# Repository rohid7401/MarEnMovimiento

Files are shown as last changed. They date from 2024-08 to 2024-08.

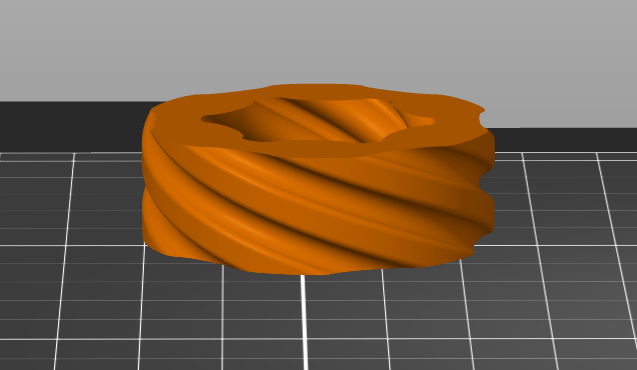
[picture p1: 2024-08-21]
Pruebas/Rosca Front.png

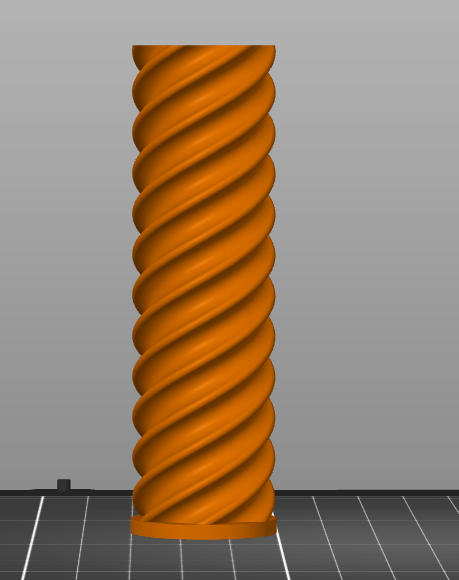
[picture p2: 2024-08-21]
Pruebas/Cilindro Front.png

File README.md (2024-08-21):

# MarEnMovimiento
Proyecto para CENFOTEC por Michelle Gutierrez, Rohi Prendas y Jeaustin  Obando

# **Proyecto: Mar en Movimiento**

## **Descripción**

Este proyecto consiste en un generador de energía que aprovecha el movimiento de las olas atravez de los geiser para producir electricidad. El dispositivo utiliza el movimiento de un cilindro y un sistema de engranajes para convertir la energía cinética de las olas en energía eléctrica. Un puente rectificador convierte la corriente alterna generada por el motor en corriente continua para alimentar LEDs u otros pequeños dispositivos electrónicos.

## **Características del Proyecto**

- **Conversión de Energía Cinética:** El dispositivo convierte el movimiento de las olas en energía eléctrica.
- **Generación en Ambos Sentidos:** Utiliza un puente rectificador para asegurar que la electricidad se genera tanto cuando la ola impacta el dispositivo como cuando el agua retrocede.
- **Indicadores LED:** Los LEDs se utilizan como indicadores visuales para mostrar la energía generada.

## **Componentes del Proyecto**

1. **Motor Generador:** Convierte el movimiento en energía eléctrica.
2. **Puente Rectificador (DF08):** Convierte la corriente alterna del motor en corriente continua.
3. **Capacitor:** Ayuda a estabilizar la salida de corriente.
4. **Engranajes:** Aumentan la eficiencia de la conversión de energía.
5. **LEDs:** Muestran la energía generada.

## **Especificaciones Técnicas**

- **Cilindro:** Crea el movimiento del engranaje que es el que provee energia.
- **Frecuencia de Activación:** Calculada en función del número de subidas y el tiempo.
- **Materiales Resilientes:** Se sugiere el uso de materiales resistentes a la corrosión debido al ambiente marino.

## **Instrucciones de Montaje**

1. **Imprimir las Piezas en 3D:**
   - Cilindro con forma de tornillo.
   - Engranajes.
   - Carcasa para mantener los componentes
   
2. **Montaje del Sistema:**
   - Conectar el motor a los engranajes.
   - Conectar el puente rectificador al motor.
   - Colocar el capacitor y los LEDs en paralelo con la salida del puente rectificador.

3. **Instalación del Dispositivo en el Agua:**
   - Asegúrate de que el dispositivo esté bien sellado para evitar daños por el agua.
   - Fija el dispositivo en una ubicación donde reciba el impacto de las olas.

## **Funcionamiento**

El dispositivo se activa con el impacto del agua disparada por el geiser. El motor genera electricidad que es convertida en corriente continua por el puente rectificador, alimentando así los LEDs. La frecuencia con la que se activa el dispositivo depende del movimiento del agua.

## **Pruebas**
Drive de las evidencia de pruebas: https://drive.google.com/drive/folders/1p6oiQmE6wtrTuFcZD503JOJJFgEpMvDa

## **Posibles Mejoras y Extensiones**

- **Implementación de un Joystick:** Para controlar la apertura de la entrada de agua, optimizando la eficiencia del sistema.
- **Análisis de Materiales:** Evaluar el uso de materiales más resistentes para entornos marinos.
- **Ampliación a Gran Escala:** Investigar la viabilidad de escalar el dispositivo para alimentar sistemas más grandes, como una vivienda.

## **Conclusión**

Este proyecto demuestra cómo se puede aprovechar la energía del movimiento del mar para generar electricidad de manera eficiente. Es un prototipo funcional que abre la puerta a futuras investigaciones y desarrollos en el campo de la energía renovable.

## **Autores**

- Michelle Gutierrez Araya
- Rohi Prendas
- Jeaustin  Obando
  
## **Licencia**
Al desarrollar y utilizar este proyecto se aceptaron los terminos y condiciones de la universidad CENFOTEC, y además se establecen los siguientes puntos:

- Uso Libre: Puede usar, copiar, modificar y distribuir el proyecto con cualquier propósito, siempre que se respeten los términos de la licencia.
- Distribución: Si distribuye copias o modificaciones del proyecto, debe incluir una copia de esta licencia.
- Limitación de Responsabilidad: Este proyecto se proporciona "tal cual", sin garantía de ningún tipo, expresa o implícita, incluyendo pero no limitándose a garantías de comerciabilidad, idoneidad para un propósito particular y no infracción.
- Citación: Si utiliza este proyecto en su investigación o trabajo, se recomienda citar al autor y el proyecto como fuente.

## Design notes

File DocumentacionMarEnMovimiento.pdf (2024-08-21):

Mar en movimiento
Tecnológico de Costa Rica

## Título del Proyecto:

## Mar en movimiento

## Energia renovable

# Participación en CENFOTEC

## Fecha: 17/8/2024

## Autores:

## - Michelle Gutiérrez Araya

## - Rohi Prendas Regalado

## - Jeaustin Obando Arias

## Índice

1. Introducción

1.1 Propósito

Este documento es una descripción técnica del proyecto del mar en movimiento. Su objetivo es ayudar a que otros ingenieros, técnicos o investigadores comprendan, puedan replicar y evalúen el proyecto de manera competente.

1.2 Alcance

Se desea desarrollar un prototipo que consiga convertir la energía del agua en electricidad. La

atención se centrará en determinar con qué eficiencia el sistema puede generar energía a

pequeña escala, con el objetivo de permitir su expansión y uso en un entorno práctico. Como

detalle, el prototipo incluye un eje giratorio, engranajes, un motor de corriente continua, un

puente rectificador, RFID, un IDEBOARD y un sistema de indicadores LED.

1.3 Objetivos

- Fabricar un prototipo funcional que capture la energía de las olas.
- Conseguir la mejor eficiencia del sistema utilizando una relación de engranajes

adecuada.

- Aplicar y diseñar un circuito eléctrico que convierta la energía alterna generada en

corriente continua.

- Evaluar la idoneidad del proyecto para entornos controlados y su viabilidad para su

implementación a gran escala.

2. Descripción del Sistema

2.1 Composición del Sistema

## El sistema tiene una base de madera para soportar el mecanismo y el dispositivo, en cuanto al mecanismo está conformado por pieza creadas con impresión 3D que

mueven el eje del motor generando energía que llega al circuito formado.

## El sistema funciona aprovechando los geiseres naturales o artificiales, que generan

mucha agua elevada a presión, que se puede aprovechar con el dispositivo creado.

La base de madera sostiene el mecanismo de un eje central interior que, rota por su enrosque con una especie de tuerca estática. La rosca al estar unida al tazón de impacto que es impulsado por el agua de forma vertical, este mueve la rosca por consecuente de manera recta y horizontal, generando que gire el eje interior rotando

junto a los ejes, los cuales están acoplados al eje del motor.

## Después de que el motor genere energía por el movimiento del mecanismo, el circuito

será energizado de manera que logra encender un led en modo de evidencia.

2.1.1 Componentes Físicos

- Eje Giratorio
- Engranajes:
- Engranaje Grande
- Engranaje Pequeño
- Motor de Corriente Continua (DC): Motor de 5V y 12,000 RPM utilizado para la

generación de electricidad.

- Puente Rectificador (DF08): Componente utilizado para convertir la corriente alterna

en corriente continua.

- Indicadores LED: Utilizados para visualizar la generación de energía.
- Carcasa Protectora: Fabricada en impresora 3D.
- Componentes de Kit

2.1.2 Circuito Eléctrico

Para este dispositivo el circuito eléctrico incluye de un motor DC conectado a un puente

rectificador que convierte la corriente alterna generada en corriente continua. Además, se

detalla que este circuito permite alimentar los LEDs y cualquier otro dispositivo de baja

potencia conectado al sistema. Además, se implementó el uso de un Ideaboard, para poder

asimismo emplear el RFID dentro del mecanismo, aclarando que no está unido al anterior

circuito sino es uno aparte.

2.2 Principio de Operación

El sistema está diseñado para captar la energía cinética de las olas mediante el fenómeno

natural llamado geiser, el cual puede ser creado natural o artificialmente a la orilla de la costa,

el dispositivo posee un eje giratorio impulsado por el impacto del agua disparada. Este

movimiento rotacional se transmite al motor con engranajes, multiplicando las RPM del

motor y optimizando la generación de energía. El puente rectificador asegura que la corriente

generada se convierta adecuadamente para su uso.

3. Diseño y Desarrollo

3.1 Diseño Mecánico

El diseño mecánico del prototipo está centrado en la maximización de la eficiencia de captura

de energía. En el cual con la espiral seleccionada del eje para asegurar que, con un impacto

que se genera por medio del mar, el eje se mueve con suficiente fuerza para generar

electricidad. Los engranajes están seleccionados para proporcionar una relación de

transmisión óptima, lo que aumenta el número de vueltas del motor con respecto al

movimiento del eje.

3.2 Diseño Eléctrico

Ahora el diseño del circuito que incluye un motor DC y un puente rectificador. El motor está

configurado para generar corriente alterna cuando el eje gira en ambas direcciones, y el

puente rectificador asegura que esta corriente se convierta en continua, adecuada para cargar

baterías o encender LEDs.

### 1. Motor:

- El motor será impulsado por el movimiento del eje, generando corriente alterna (AC)

cuando gira en cualquier dirección.

### 2. Puente Rectificador de Diodos (DF08):

- Este componente tiene cuatro terminales:
- AC1 y AC2: Conectados a las terminales del motor.
- + (Positivo): Conectado al lado positivo del capacitor y al LED.
- - (Negativo): Conectado al lado negativo del capacitor y al emisor del

transistor 2N2222.

### 3. Capacitor (Opcional):

- Capacitor de 100 µF: Almacena energía temporalmente para suavizar la salida del

puente rectificador, asegurando que el LED reciba una corriente más estable.
- Conectado en paralelo al LED y al puente rectificador, entre las terminales + y -.
4. LED:

- Conectado entre el + y - del puente rectificador.
5. RFID-RC522:
- Conectado al ideaboard.
6. IDEABOARD:
- Programado y alimentado por la laptop.

## 3.3 Diseño de la Programación

El diseño de la programación del sistema se basó en los recursos y tutoriales proporcionados por la Universidad CENFOTEC, lo que facilitó la integración de los diferentes componentes del proyecto.

Para la programación, se utilizó el software Thonny en combinación con CircuitPython, que es el lenguaje de programación utilizado para el IdeaBoard. Los tutoriales de la universidad fueron fundamentales, ya que proporcionaron las bases necesarias para comprender cómo programar en este entorno, así como la manipulación del hardware a través del código.

3.3.1 Uso de Tutoriales y Recursos

Se siguieron específicamente los tutoriales proporcionados por la universidad para trabajar con el módulo RFID. A partir de estos, se descargó la librería mfrc522, que es esencial para la comunicación con el lector RFID RC522. Además, se utilizaron tres códigos de ejemplo disponibles en el repositorio de la universidad para realizar las operaciones básicas: lectura, escritura y pruebas con LEDs al detectar una tarjeta o un llavero RFID.

3.3.2 Integración con el Kit ExpoCenfo

Al acceder al repositorio de la universidad en GitHub, ExpoCenfo, (https://github.com/Universidad-Cenfotec/ExpoCenfo) se encontró información valiosa y códigos de ejemplo para otros componentes incluidos en el Kit ExpoCenfo, utilizado en el desarrollo del sistema. Entre estos componentes se incluye la pantalla LCD1602, que fue otro elemento clave en el proyecto. Para utilizarla, se descargaron las librerías i2c_pcf8574_interface y LCD, también disponibles en el repositorio.

El código de ejemplo para la pantalla LCD se utilizó como base para el desarrollo del archivo code.py, que es el script principal ejecutado al iniciar el IdeaBoard. Este código permite la interacción entre el RFID y la pantalla LCD, gestionando la visualización de mensajes y datos en tiempo real.

## 3.3.3 Código principal [ code.py ]

El código principal code.py está diseñado para gestionar la interacción con un sistema de detección y monitorización de géiseres utilizando un microcontrolador IdeaBoard (basado en el ESP32), un lector RFID RC522 y una pantalla LCD 16x2. A continuación, se detalla el funcionamiento de este código.

## 3.3.3.1 Inicialización de Componentes

- Pantalla LCD:
- Se inicializa una pantalla LCD de 16 columnas y 2 filas utilizando la interfaz I2C. Esta pantalla se usa para mostrar mensajes y datos, como el número de géiseres detectados y la frecuencia de erupción.
- La pantalla se configura con la dirección I2C 0x27.
- Lector RFID RC522:
- Se configura el lector RFID RC522 utilizando los pines de comunicación SPI. Este lector es responsable de detectar y comunicarse con las tarjetas RFID.
- Se ajusta la ganancia de la antena para mejorar la sensibilidad del lector.
- IdeaBoard:
- Se inicializa la IdeaBoard, que es el microcontrolador central encargado de gestionar el hardware y ejecutar el código. En este caso, el código está escrito en CircuitPython y corre en la IdeaBoard.

## 3.3.3.2 Variables y Configuración Inicial

- Variables Globales:
- num_geisers: Almacena el número de géiseres detectados. Esta variable se actualiza cada vez que se detecta un nuevo géiser y se guarda en la tarjeta RFID.
- frecuencia: Representa el tiempo entre erupciones de géiseres, calculado en segundos.
- ultimo_geiser: Almacena la marca de tiempo de la última detección de un géiser, utilizada para calcular la frecuencia de erupción.
- Mensaje Rotativo:
- Un mensaje predefinido, "MarEnMovimiento", se configura para desplazarse de derecha a izquierda en la pantalla LCD, creando un efecto visual atractivo. Este mensaje se muestra cuando el sistema está en espera, es decir, cuando no se está mostrando información sobre géiseres.

## 3.3.3.3 Funciones Principales

mostrar_mensaje:
- Esta función muestra el mensaje "MarEnMovimiento" desplazándose continuamente en la pantalla LCD. La función limpia la pantalla, calcula la subcadena visible del mensaje y la muestra, creando un efecto de rotación que simula un cartel digital en movimiento.
mostrar_datos:
- Muestra en la pantalla LCD el número de géiseres detectados y la frecuencia de erupción. La información se muestra en dos líneas: la primera línea muestra el número de géiseres (Geiser #X), y la segunda línea muestra la frecuencia (Freq: ~X.XX).
mostrar_mensaje_temporal:
- Muestra un mensaje específico en la pantalla LCD durante un tiempo determinado (en segundos). Esta función es utilizada, por ejemplo, para notificar al usuario que se ha detectado un géiser.
leer_tarjeta:
- Esta función maneja la interacción con la tarjeta RFID. Primero, detecta si una tarjeta está presente. Luego, intenta autenticarse con la tarjeta utilizando la clave predeterminada.
- Si la autenticación es exitosa, lee los datos almacenados en la tarjeta, actualiza el número de géiseres y la frecuencia, y finalmente reautentica la tarjeta para escribir los datos actualizados.
- Si la autenticación o la escritura falla, la función imprime un mensaje de error para depuración.

## 3.3.3.4 Bucle Principal

El bucle principal del código controla el flujo continuo de operaciones:

- Visualización del Mensaje Rotativo:
- Al inicio del programa, se muestra el mensaje rotativo "MarEnMovimiento". Este mensaje permanece en pantalla hasta que se detecta un nuevo evento, como la necesidad de mostrar los datos de un géiser.
- Control de Tiempo:
- Cada 10 segundos, el sistema interrumpe el mensaje rotativo para mostrar los datos actuales del número de géiseres y la frecuencia de erupción. Estos datos se muestran durante 4 segundos antes de volver a mostrar el mensaje rotativo.
- Detección de Tarjetas RFID:
- Durante cada iteración del bucle, el sistema está constantemente escuchando por la presencia de una tarjeta RFID. Si se detecta una tarjeta, se ejecuta la función leer_tarjeta, que maneja la lectura y actualización de los datos en la tarjeta.
- Pequeñas Pausas (time.sleep):
- Se utilizan pequeñas pausas (time.sleep(0.1)) para evitar que el bucle se ejecute demasiado rápido, lo que podría causar un consumo innecesario de recursos o interferir con las operaciones de lectura/escritura.

4. Implementación

4.1 Fabricación

La fabricación del prototipo incluyó la nueva idea del mecanismo y cómo funciona el mismo

al combinar cada una de sus partes. Y la integración de componentes electrónicos como el

motor, puente rectificador y los leds. La creación de su base y lógica detrás de la

representación del efecto del agua para conseguir la evidencia de forma casera. La impresión

3D de los componentes mecánicos se hicieron en un lugar controlado por nosotros, los

engranajes y la carcasa donde se ingresaron los componentes se pueden generar de manera

simple.

4.2 Ensamblaje Simple

El ensamblaje se realizó siguiendo un proceso sistemático:

- Montaje del eje giratorio en la carcasa protectora.
- Acoplamiento de los engranajes al eje y al motor.
- Conexión del circuito eléctrico al motor y a los LEDs.
- Pruebas preliminares para asegurar la correcta operatividad del sistema.

5. Pruebas y Validación

5.1 Métodos de Prueba

El sistema fue sometido a varias pruebas para validar su operatividad:

- Pruebas de laboratorio: Simulaciones de impacto de olas para evaluar la capacidad de

generación de energía.

- Pruebas de campo: Evaluación en un entorno controlado cercano a la costa para

verificar la resistencia y eficiencia del sistema en condiciones reales.

5.2 Resultados

Los resultados mostraron que el prototipo puede generar suficiente energía para alimentar

LEDs bajo condiciones óptimas. Sin embargo, su eficiencia disminuye con olas de menor

intensidad.

6. Conclusiones

6.1 Resumen

El proyecto logró demostrar la viabilidad de utilizar la energía de la fuerza de agua para

generar electricidad en pequeña escala. La relación de transmisión y el diseño del eje fueron

claves para maximizar la captura de energía.

6.2 Limitaciones

El prototipo mostró limitaciones en la generación de energía bajo condiciones de olas fuertes

atreves de un geiser, lo que podría requerir mejoras en el diseño para aplicaciones a gran

escala.

En la elaboración del prototipo, se establecieron las dimensiones máximas permitidas,

limitando las medidas para no superar los 20 centímetros en largo, ancho o altura. Esta

restricción se implementó para asegurar la compatibilidad con la impresora 3D utilizada,

cuya capacidad de impresión está limitada a estas dimensiones. Respetar estas medidas es

fundamental no solo para garantizar la viabilidad técnica del proceso de impresión, sino

también para optimizar el uso del material y reducir el tiempo de producción.

6.3 Recomendaciones

Se sugiere optimizar el diseño del eje y la relación de transmisión de los engranajes para

mejorar la eficiencia del sistema. Además, se recomienda el uso de materiales más avanzados

para aumentar la durabilidad en condiciones marinas.

Al diseñar cualquier modelo en 3D, es recomendable considerar las limitaciones técnicas de

la impresora 3D que se utilizará, especialmente en cuanto a las dimensiones máximas de

impresión. Mantener el modelo dentro de estos límites no solo asegura la viabilidad del

proyecto, sino que también mejora la precisión y la calidad del resultado final.

7. Anexos

7.1 Planos y Esquemas

- Esquema Eléctrico: Diagrama detallado del circuito utilizado.
- Planos Mecánicos: Diagramas del diseño del eje y los engranajes.

Diagramas de la carcasa.

- Impresión 3D:

Los materiales utilizados para todas las impresiones son PLA este material es el

filamento que la impresora para mayor dinámica en las distintas piezas se utilizó

distintos colores.

Cilindro:

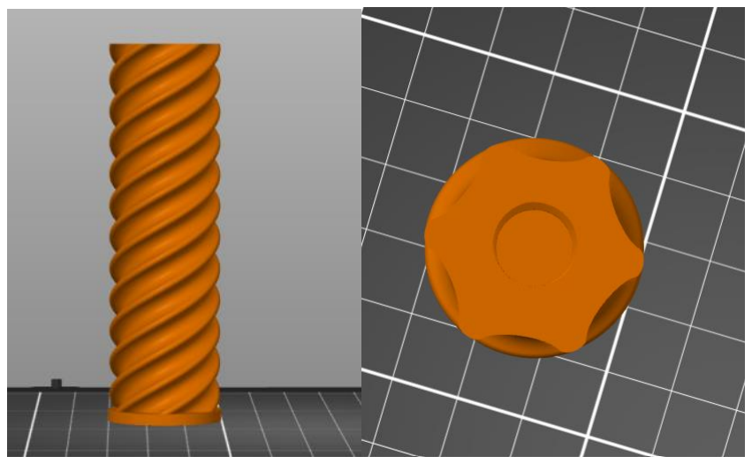
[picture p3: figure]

Rosca:

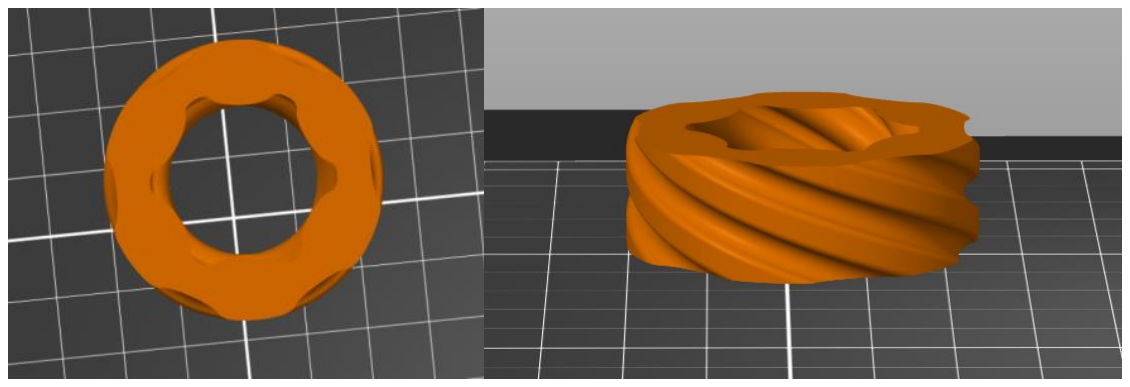
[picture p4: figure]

## Caja:

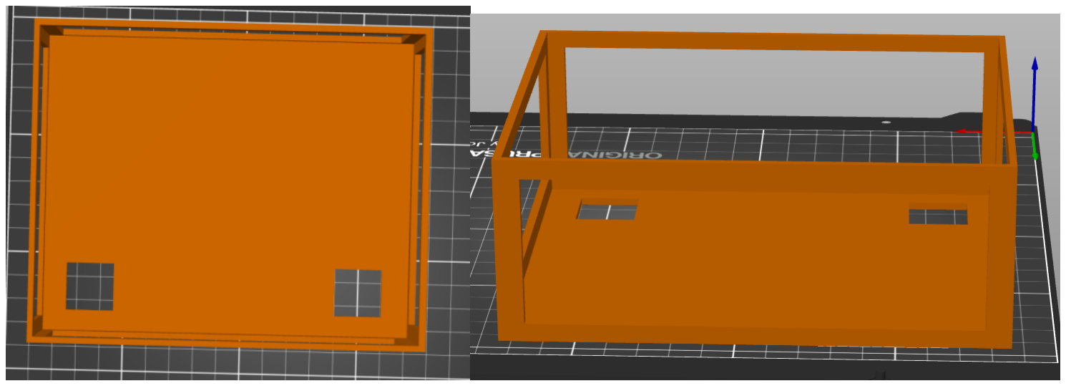
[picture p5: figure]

## El modelo de la caja fue realizado con la aplicación Blender esta misma fue desarrollado con booleanos esto mismo permitió realizar las distintas perforaciones y accesos que el espacio lo necesitara sus dimensiones son 16

cm de ancho, 13 cm de largo y 6 cm de alto.

## Tapa del Cilindro:

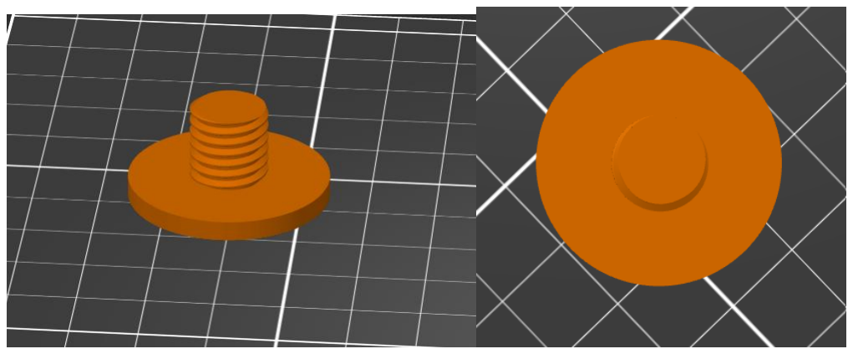
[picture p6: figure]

## Engranaje Grande:

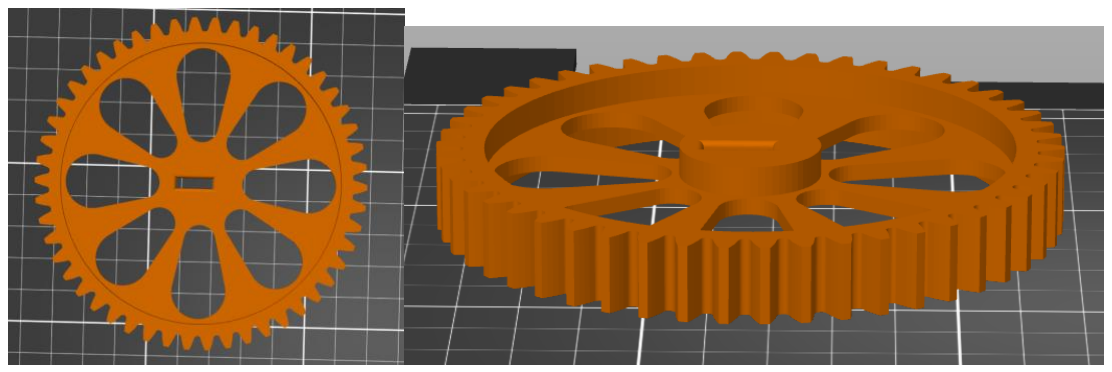
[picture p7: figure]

## Engranaje Chico:

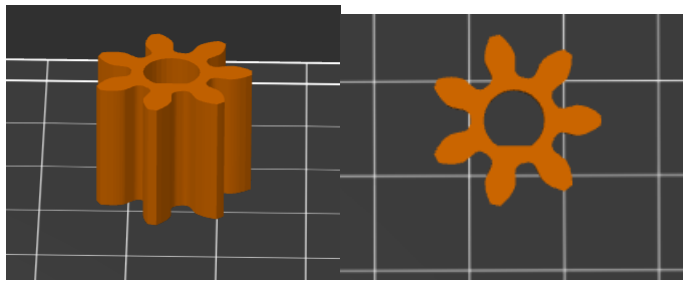
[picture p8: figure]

7.2 Cálculos de Potencia

- Detalle de los cálculos de potencia generada por el motor en función de las RPM y la

intensidad de las olas.

7.3 Referencias

- Documentación Técnica de Componentes: Especificaciones de los componentes

utilizados, incluidas las fichas técnicas.

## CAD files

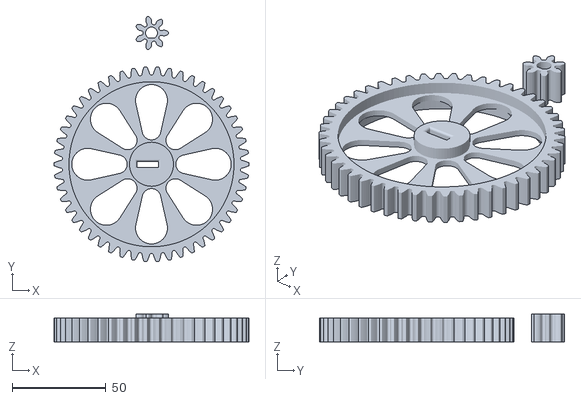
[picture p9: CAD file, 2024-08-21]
Diseños de Impresion 3D/SmartLock_Gears_v3.stl
104.0 x 130.8 x 14.7

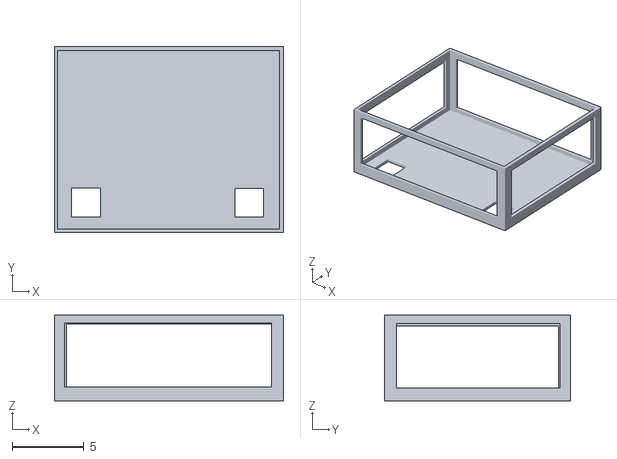
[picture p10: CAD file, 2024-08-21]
Diseños de Impresion 3D/caja_prueba.stl
16.0 x 13.0 x 6.00

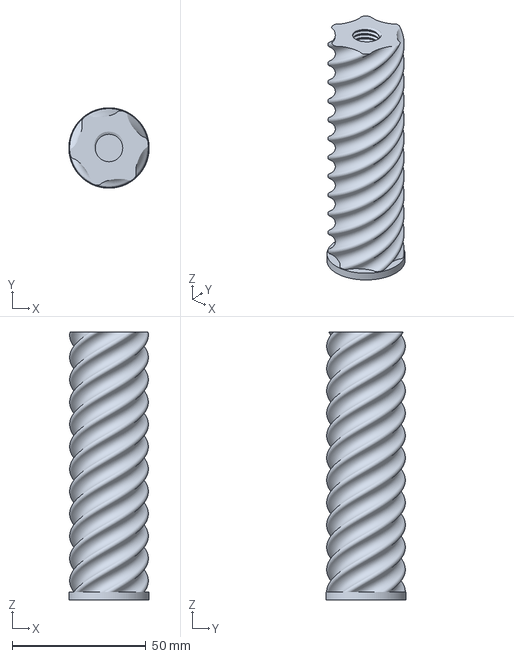
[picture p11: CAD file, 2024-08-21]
Diseños de Impresion 3D/Screw.3mf
30.0 x 30.0 x 100.0 mm

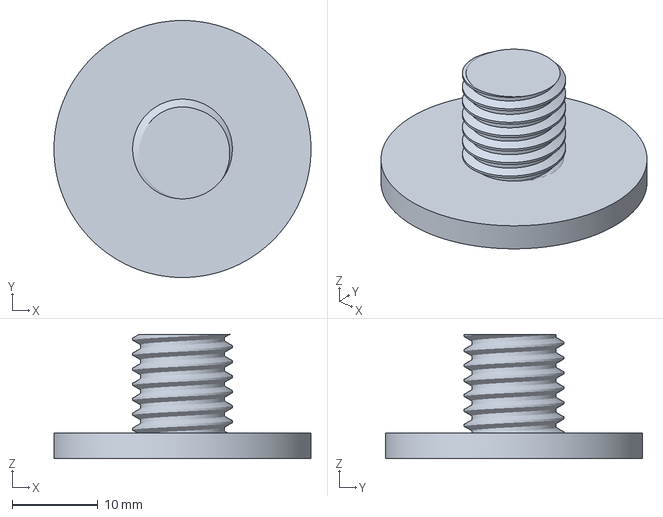
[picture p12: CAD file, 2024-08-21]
Diseños de Impresion 3D/Screw cap.3mf
30.0 x 30.0 x 14.5 mm

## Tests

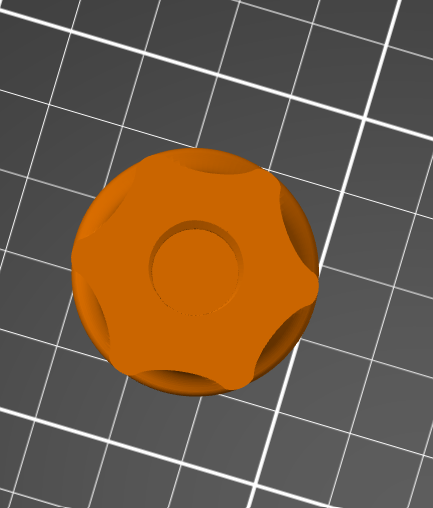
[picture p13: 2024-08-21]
Pruebas/Cilindro Top.png

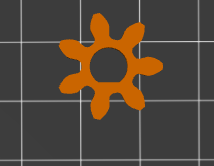
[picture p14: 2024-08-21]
Pruebas/Engranaje Chico Top.png

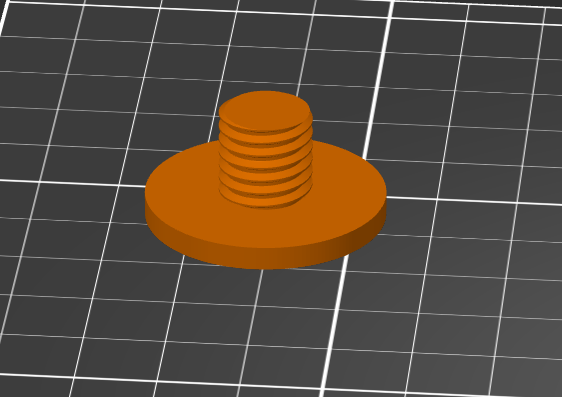
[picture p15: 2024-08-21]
Pruebas/Tapa de cilindro front.png

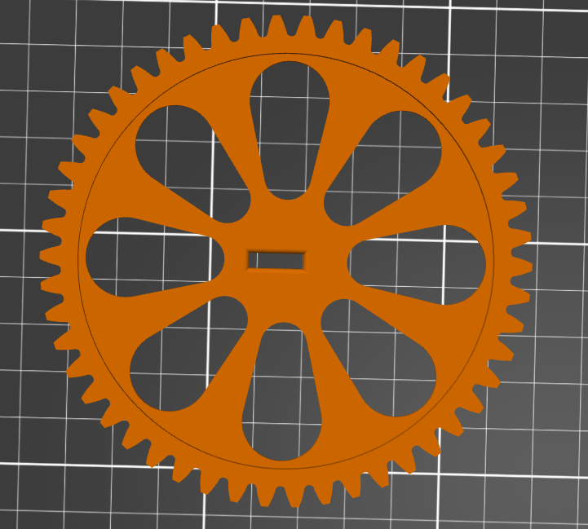
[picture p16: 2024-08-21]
Pruebas/Engranaje Grande Top.png

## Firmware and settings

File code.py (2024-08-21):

import time
import board
import busio 
from lcd import LCD
from i2c_pcf8574_interface import I2CPCF8574Interface
import mfrc522
from ideaboard import IdeaBoard
 
# Configuración de la pantalla LCD
lcd_columns = 16  # Número de columnas del LCD (caracteres por línea)
lcd_rows = 2      # Número de filas del LCD
i2c = board.I2C()  # Inicialización del bus I2C en los pines predeterminados
lcd = LCD(I2CPCF8574Interface(i2c, 0x27), num_rows=lcd_rows, num_cols=lcd_columns)
# Crea una instancia de la pantalla LCD utilizando la interfaz I2C
 
# Configuración del lector RFID
lector = mfrc522.MFRC522(
    board.SCK,  # Pin para la línea de reloj serial (SCK)
    board.MOSI, # Pin para la línea de datos (MOSI)
    board.MISO, # Pin para la línea de datos (MISO)
    board.IO4,  # Pin para la línea de reinicio (RST)
    board.IO5,  # Pin para la línea de selección de esclavo (SDA)
)
lector.set_antenna_gain(0x07 << 4)  # Ajuste de la ganancia de la antena para mejorar la sensibilidad

# Inicialización de IdeaBoard
ib = IdeaBoard()  # Inicializa la IdeaBoard, que gestiona el hardware en el proyecto

# Inicialización de variables
num_geisers = 0  # Variable para almacenar el número de géiseres detectados
frecuencia = 0.0  # Variable para almacenar la frecuencia (tiempo entre erupciones)
ultimo_geiser = time.time()  # Almacena el tiempo del último géiser detectado

# Mensaje a rotar
mensaje = "MarEnMovimiento   "  # Mensaje a mostrar en la pantalla LCD, con espacios para crear un efecto de desplazamiento
lenmsg = len(mensaje)  # Longitud del mensaje, incluyendo los espacios

# Función para mostrar mensaje "MarEnMovimiento"
def mostrar_mensaje():
    """
    Muestra un mensaje desplazado en la pantalla LCD. El mensaje se mueve de derecha a izquierda,
    creando un efecto de rotación.
    """
    lcd.clear()  # Limpia la pantalla antes de comenzar
    for i in range(lenmsg + lcd_columns):
        lcd.clear()
        # Determina el índice inicial de la subcadena y la longitud visible del mensaje
        inicio = i % lenmsg
        if inicio + lcd_columns <= lenmsg:
            lcd.print(mensaje[inicio:inicio + lcd_columns])  # Muestra una parte del mensaje
        else:
            lcd.print(mensaje[inicio:] + mensaje[:lcd_columns - (lenmsg - inicio)])  # Muestra la parte restante del mensaje en la siguiente vuelta
        time.sleep(0.3)  # Pausa para controlar la velocidad del desplazamiento del mensaje
 
# Función para mostrar los datos del géiser y la frecuencia en la pantalla LCD
def mostrar_datos():
    """
    Limpia la pantalla LCD y muestra el número de géiseres detectados y la frecuencia
    de erupción en segundos. La información se muestra en dos líneas:
    - Línea 1: Número de géiseres detectados.
    - Línea 2: Frecuencia (~tiempo entre erupciones) en segundos.
    """
    lcd.clear()  # Limpia la pantalla LCD
    lcd.set_cursor_pos(0, 0)  # Coloca el cursor en la primera fila, primer carácter
    lcd.print(f"Geiser #{num_geisers}")  # Muestra el número de géiseres detectados
    lcd.set_cursor_pos(1, 0)  # Coloca el cursor en la segunda fila, primer carácter
    lcd.print(f"Freq:~{frecuencia:.2f}")  # Muestra la frecuencia de erupción con dos decimales

# Función para mostrar un mensaje temporal en la pantalla LCD
def mostrar_mensaje_temporal(mensaje, duracion=1):
    """
    Muestra un mensaje específico en la pantalla LCD durante un tiempo determinado.
    Luego, limpia la pantalla.
    
    Parámetros:
    - mensaje: El mensaje que se mostrará en la pantalla LCD.
    - duracion: La cantidad de tiempo (en segundos) que el mensaje se mostrará antes de limpiar la pantalla.
    """
    lcd.clear()  # Limpia la pantalla LCD antes de mostrar el mensaje
    lcd.set_cursor_pos(0, 0)  # Coloca el cursor en la primera fila, primer carácter
    lcd.print(mensaje)  # Muestra el mensaje en la pantalla LCD
    time.sleep(duracion)  # Espera el tiempo especificado (duracion)
    lcd.clear()  # Limpia la pantalla LCD después de mostrar el mensaje

 
# Función para leer y actualizar datos en la tarjeta RFID
def leer_tarjeta():
    """
    Lee los datos almacenados en la tarjeta RFID y actualiza el número de géiseres detectados y la frecuencia.
    Primero, intenta autenticarse para leer los datos. Si tiene éxito, incrementa el número de géiseres y calcula
    la nueva frecuencia basada en el tiempo desde la última erupción. Luego, intenta autenticarse nuevamente para 
    escribir los datos actualizados en la tarjeta.

    Esta función maneja la detección de una tarjeta RFID, la lectura de los datos existentes, la actualización de los 
    datos, y la escritura de los datos actualizados en la tarjeta.
    """
    global num_geisers, frecuencia, ultimo_geiser  # Variables globales para almacenar el estado del sistema
    try:
        estado, tipo_tarjeta = lector.request(lector.REQIDL)  # Solicita la presencia de una tarjeta RFID

        if estado == lector.OK:
            estado, uid = lector.anticoll()  # Detecta la tarjeta y obtiene su UID

            if estado == lector.OK:
                mostrar_mensaje_temporal("Geiser Detectado")  # Muestra un mensaje temporal en la pantalla LCD

                if lector.select_tag(uid) == lector.OK:  # Selecciona la tarjeta detectada para realizar operaciones
                    clave = [0xFF, 0xFF, 0xFF, 0xFF, 0xFF, 0xFF]  # Clave predeterminada para la autenticación

                    # Intentar autenticación para lectura
                    if lector.auth(lector.AUTHENT1A, 8, clave, uid) == lector.OK:
                        datos = lector.read(8)  # Lee los datos del bloque 8 de la tarjeta
                        num_geisers = datos[0]  # Actualiza el número de géiseres con el valor leído
                        print(f"Data en tarjeta={datos}")  # Imprime los datos leídos para depuración

                        # Intentar autenticación nuevamente para escritura
                        if lector.auth(lector.AUTHENT1A, 8, clave, uid) == lector.OK:
                            num_geisers += 1  # Incrementa el número de géiseres detectados

                            # Calcular la nueva frecuencia basada en el tiempo desde la última erupción
                            tiempo_actual = time.time()
                            tiempo_entre_geisers = tiempo_actual - ultimo_geiser  # Calcula la frecuencia de erupciones
                            ultimo_geiser = tiempo_actual  # Actualiza el tiempo del último géiser detectado
                            frecuencia = tiempo_entre_geisers  # Actualiza la frecuencia con el tiempo calculado

                            # Preparar los datos a escribir en la tarjeta RFID
                            datos_a_escribir = bytearray([num_geisers, int(frecuencia)] + [0x00] * 14)
                            estado = lector.write(8, datos_a_escribir)  # Escribe los datos actualizados en la tarjeta
                            print(f"Nueva data ={datos_a_escribir}")  # Imprime los nuevos datos para depuración
                            lector.stop_crypto1()  # Finaliza la operación criptográfica

                            if estado == lector.OK:
                                print("Geiser Detectado")  # Confirma que la escritura fue exitosa
                            else:
                                print("Error en la escritura")  # Indica un error en la escritura de datos
                        else:
                            print("Error de autenticación al escribir")  # Indica un error en la autenticación para escritura
                    else:
                        print("Error de autenticación al leer")  # Indica un error en la autenticación para lectura
            else:
                print("Error seleccionando la tarjeta")  # Indica un error al seleccionar la tarjeta detectada
    
    except KeyboardInterrupt:
        print("Detenido por Ctrl+C")  # Maneja la interrupción del teclado para detener el programa de forma segura

 
# Bucle principal
mostrar_mensaje()  # Muestra el mensaje "MarEnMovimiento" en la pantalla LCD al iniciar
ultimo_cambio = time.monotonic()  # Registra el tiempo inicial para controlar la visualización de datos

while True:
    tiempo_actual = time.monotonic()  # Obtiene el tiempo actual para comparar con el último cambio
    # Cada 10 segundos muestra los datos durante 4 segundos
    if tiempo_actual - ultimo_cambio >= 10:
        mostrar_datos()  # Muestra los datos del géiser y la frecuencia en la pantalla LCD
        time.sleep(4)  # Mantiene los datos en pantalla durante 4 segundos
        mostrar_mensaje()  # Vuelve a mostrar el mensaje "MarEnMovimiento"
        ultimo_cambio = tiempo_actual  # Actualiza el tiempo del último cambio

    # Siempre está escuchando por una tarjeta RFID
    leer_tarjeta()  # Verifica si hay una tarjeta RFID presente y realiza las acciones correspondientes
    time.sleep(0.1)  # Espera brevemente antes de la siguiente iteración del bucle

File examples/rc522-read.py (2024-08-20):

import time
import board
import mfrc522
from ideaboard import IdeaBoard


def leer_tarjeta():
    lector = mfrc522.MFRC522(
        board.SCK,  # Pin SCK
        board.MOSI,  # Pin MOSI
        board.MISO,  # Pin MISO
        board.IO4,   # Pin RST
        board.IO5,   # Pin SDA
    )

    lector.set_antenna_gain(0x07 << 4)


    print("\n Acérquese la tarjeta al lector para leer datos de la dirección 0x08 \n")
    try:
        while True:
            estado, tipo_tarjeta = lector.request(lector.REQIDL)

            if estado == lector.OK:
                estado, uid = lector.anticoll()

                if estado == lector.OK:
                    print("Nueva tarjeta detectada")
                    print("  - Tipo de tarjeta: 0x%02x" % tipo_tarjeta)
                    print("  - UID: 0x%02x%02x%02x%02x" % (uid[0], uid[1], uid[2], uid[3]))
                    print('')

                    if lector.select_tag(uid) == lector.OK:
                        clave = [0xFF, 0xFF, 0xFF, 0xFF, 0xFF, 0xFF]

                        if lector.auth(lector.AUTHENT1A, 8, clave, uid) == lector.OK:
                            datos = lector.read(8)
                            print("Datos de la dirección 8: %s" % datos)
                            lector.stop_crypto1()
                        else:
                            print("Error de autenticación")
                    else:
                        print("Error al seleccionar la tarjeta")

    except KeyboardInterrupt:
        print("Detenido por Ctrl+C")


while True:
    leer_tarjeta()

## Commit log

2024-07-31 Código de parpadedo de led
    Se copio el código mostrado en el video de ejemplo (no lo he probado)
2024-08-05 RFID arduino y adaptación python
    código para identificar un rfid rc522 y encender led
2024-08-20 Documentos Avances
    Se muestra como cambió el proyecto de su forma inicial.
2024-08-20 Librerías para el ideaboard
    Además de las que trae por defecto se agregaron:
    Para el RFID
    -MFRC522
    Para la pantalla
    -LCD
    -i2c_pcf8574_interface
2024-08-20 Códigos de ejemplo y prueba
    Además de los que trae por defecto se añaden el de prueba para la pantalla, escritura, lectura y un cambio de color de led con el RFID
2024-08-20 Código inicial de ejecución - Lógica del proyecto
    Muestra un mensaje desplazándose en la pantalla LCD y, cada 12 segundos, alterna para mostrar el número de erupciones y la frecuencia (tiempo entre erupciones). Cada vez que se detecta una tarjeta RF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
2024-08-20 Update code.py
    Se corrigue el display del nombre del proyecto
    [code.py]
2024-08-21 Acomodo de Pruebas
    [Screw cap.3mf, Screw.3mf, SmartLock_Gears_v3.stl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]
2024-08-21 Corrección de errores y documentacion interna de code.py
    se documento toda la funcion además de corregir un par de errores que estaba dando el LCD
    [code.py]
2024-08-21 Update README.md
    Se agrego el drive con las pruebas del
